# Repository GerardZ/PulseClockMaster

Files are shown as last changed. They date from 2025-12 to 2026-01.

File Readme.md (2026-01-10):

## PulseClock Master

TAGS: slaveClock slave-clock pulseclock pulse-clock secondary-clock slave clock impulse driver masterclock 

### So what is this

This is a NTP-clock which can drive a Pulse Clock/ secondary clock/ slave clock, the type of clock found in schools, stations or other big buildings. Nowadays most of them have been replaced by modern ones, but they still exists. These clocks are driven by a master clock which pulses the slave clocks every minute, where it moves the minute-hand one minute. So it acts as a masterclock for these slave clocks.
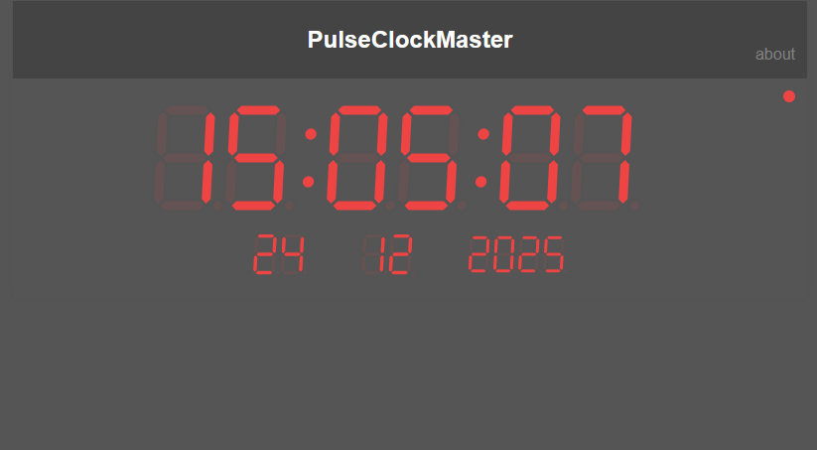
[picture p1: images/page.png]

Webpage is a mere indication of the clock, time is displayed and is coming from the ESP, it is not your pc`s time (though they should be the same). Date is displayed and there is a red dot in the top right corner which displays the state of the pulse, on = poitive, off = negative.

### Why would i need this

You might be a happy owner of such a slave clock, threw it on your attic, like me.  Always asking yourself how to enable that beautiful thing. This can be your savior. 
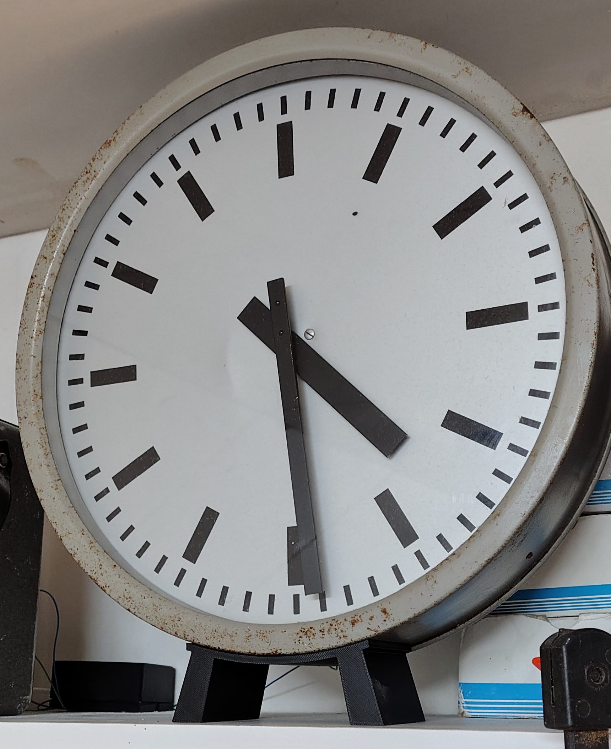
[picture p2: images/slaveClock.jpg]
My Clock:

### What do i need

*   A slave clock obviously
*   This circuitry
*   ESP01 programmer (dont let this frighten you, its a no-brainer)
*   Wifi & internet

### The Circuit

Circuit consist of a 24V power module, 3v3 step down module, an ESP01, opamp & 2 transistor driver.

<div align="center"><a href="images/schema.png" target="_blank">
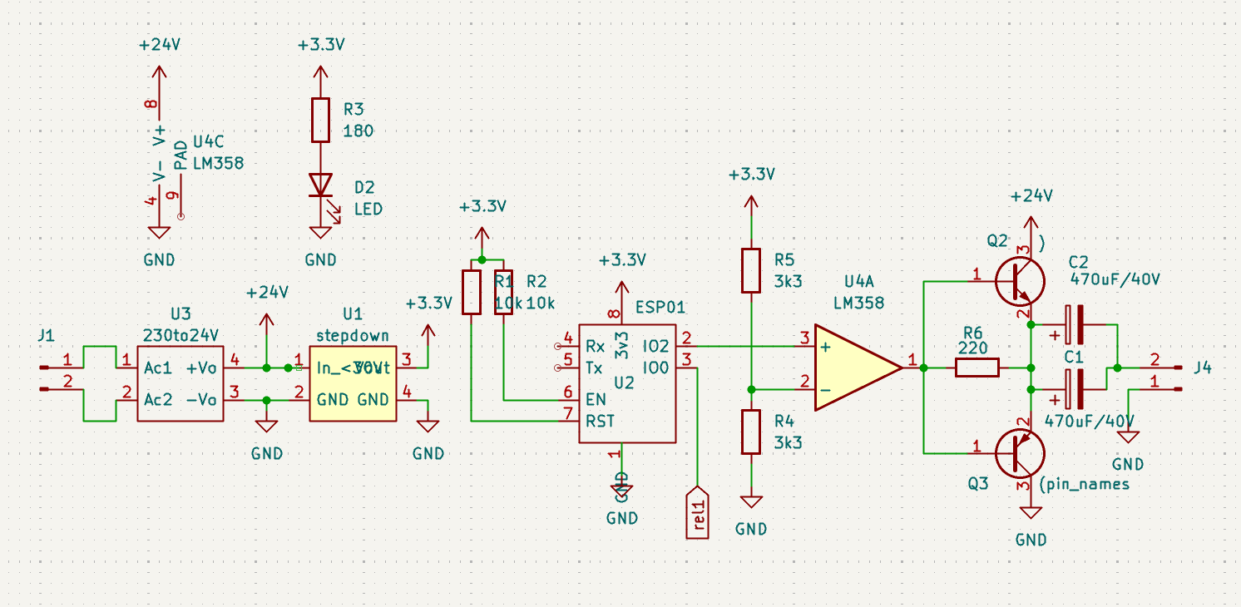
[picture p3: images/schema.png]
  
</a></div>

We need a 24V pulse to drive the clock. Pulses are given every minute where one pulse is positive, the next negative, this is done by the opamp, buffer transistors and the output electrolitic capacitors. The ESP01 pulses the opamp by AND-ing the lsb of the minutes every minute.
Internally time is handled by NTP so we never need to worry over adjusting except for power outages. Even DST is handled !
When you have multiple clocks, you probably get away with two or three, not tested. You could rise capacitance of the output capacitors by 2x 1000uF.
I am running one clock but have only installed one 470uF capacitor. That should give an indication. But I guess not all clock brands have the same load.

### The software

ESP01 firmware has a wifi portal, NTP, a webserver displaying time and pulse status. Time is updated through websockets to the webpage so even for this simple application there is already a lot going on. See for yourself !

### Using

Supply with mains, connect your clock, power up.
On first connection there will be no wifi credentials so the device will go into portal mode and starts is own wifi station with SSID: PulseClockMaster, connect to it (pw: 12345678) and open a page on your webbrowser. The portal page should come up. Enter your wifi credentials an press save. The device will reboot and connect, hopefully, to your wifi. From thereon you should be able to connect via http://PulseClockMaster.local but this depends on your router. If not try
http://PulseClockMaster. If that doesnt work still, find out what ip it is given by your router and connect via ip.
There is only a display of time and date, so this step is not even necessary but it will give you a good idea that it is all functioning well.

You will have to adjust time b hand on the physical clock once. From thereon it will be synced every minute. If you notice the clock keeps behind one minute, reverse polary on the clock and re-adjust. The latter is only nececaity once since the clock pulses depend on wether the minute is odd or even.

You only have to re-adjust after a power-failure.

### Todo\`s

*   make settings for other timezones & DST settings, now only changeable in code
*   power outage handling ?

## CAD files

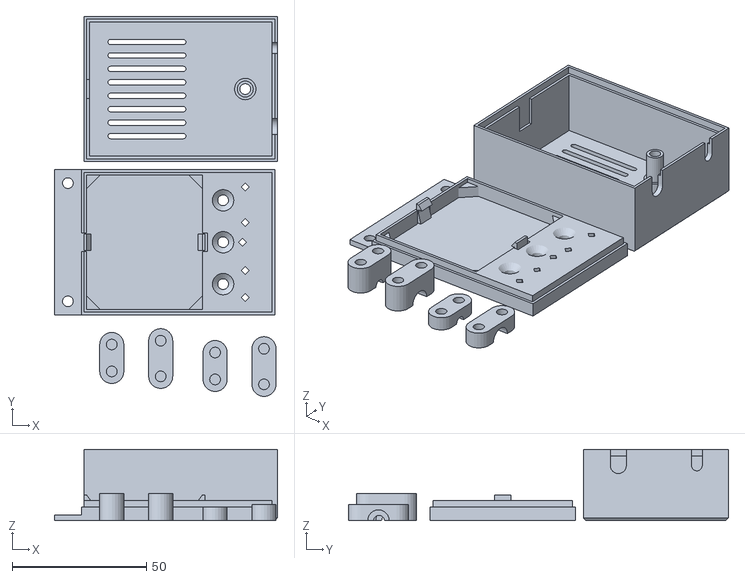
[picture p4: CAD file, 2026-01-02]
ProjectFiles/Housing/housing.stl
83.0 x 141.4 x 26.5

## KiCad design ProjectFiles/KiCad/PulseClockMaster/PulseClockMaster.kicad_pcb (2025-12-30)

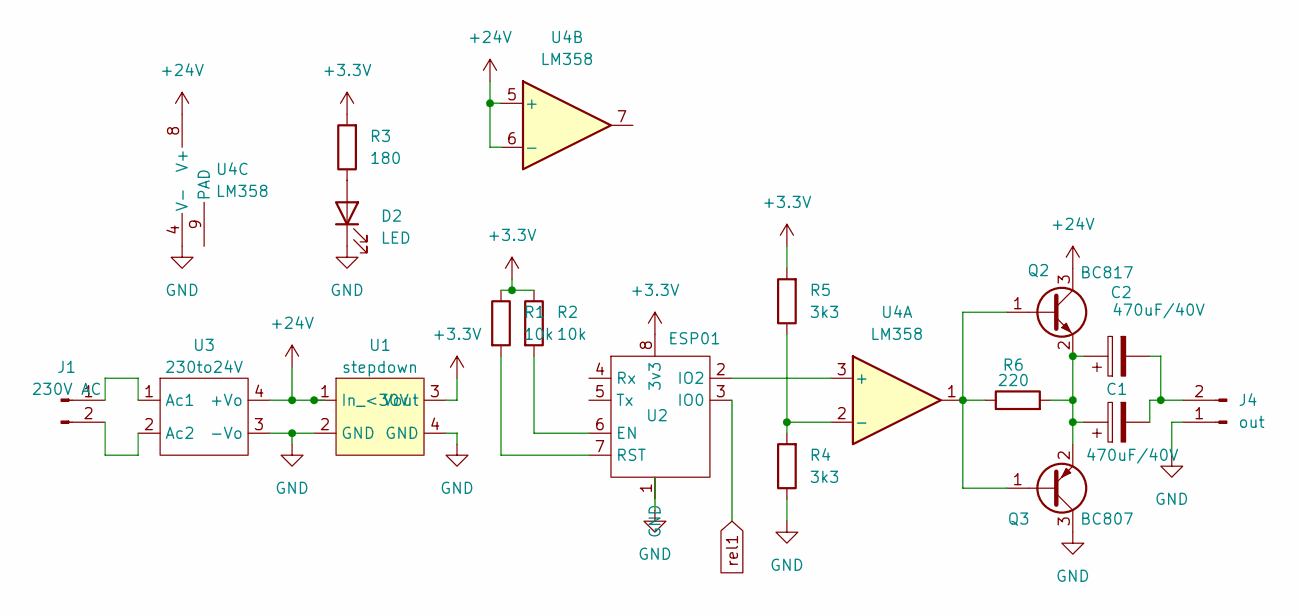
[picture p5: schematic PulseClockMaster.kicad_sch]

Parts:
C1, C2: 470uF/40V; CP_Radial_D8.0mm_P3.80mm
D2: LED; LED_D5.0mm
J1: 230V AC; TerminalBlock_MaiXu_MX126-5.0-02P_1x02_P5.00mm
J4: out; TerminalBlock_4Ucon_1x02_P3.50mm_Horizontal
Q2: BC817; SOT-23
Q3: BC807; SOT-23
R1, R2: 10k; R_0805_2012Metric_Pad1.20x1.40mm_HandSolder
R3: 180; R_0805_2012Metric_Pad1.20x1.40mm_HandSolder
R4, R5: 3k3; R_0805_2012Metric_Pad1.20x1.40mm_HandSolder
R6: 220; R_0805_2012Metric_Pad1.20x1.40mm_HandSolder
U1: stepdown; Mini-Stepdown
U2: ESP01; ESP01_conn+outline
U3: 230to24V; Mini Ac-DC 230 to 24V module EBAY
U4: LM358; SOIC-8_3.9x4.9mm_P1.27mm

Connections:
+3.3V: R1.1, R2.1, R3.2, R5.2, U1.3 (Vout), U2.8 (3v3)
+24V: Q2.3 (C), U1.1 (In_<30V), U3.4 (+Vo), U4.5 (+), U4.6 (-), U4.8 (V+)
GND: D2.1 (K), J4.1, Q3.3 (C), R4.1, U1.2 (GND), U1.4 (GND), U2.1 (GND), U3.3 (-Vo), U4.4 (V-)
unnamed: D2.2 (A), R3.1
unnamed: J1.1, U3.1 (Ac1)
unnamed: J1.2, U3.2 (Ac2)
unnamed: C1.2, C2.2, J4.2
unnamed: Q2.1 (B), Q3.1 (B), R6.1, U4.1
unnamed: C1.1, C2.1, Q2.2 (E), Q3.2 (E), R6.2
unnamed: R2.2, U2.6 (EN)
unnamed: U2.2 (IO2), U4.3 (+)
unnamed: R1.2, U2.7 (RST)
unnamed: R4.2, R5.1, U4.2 (-)
rel1: U2.3 (IO0)

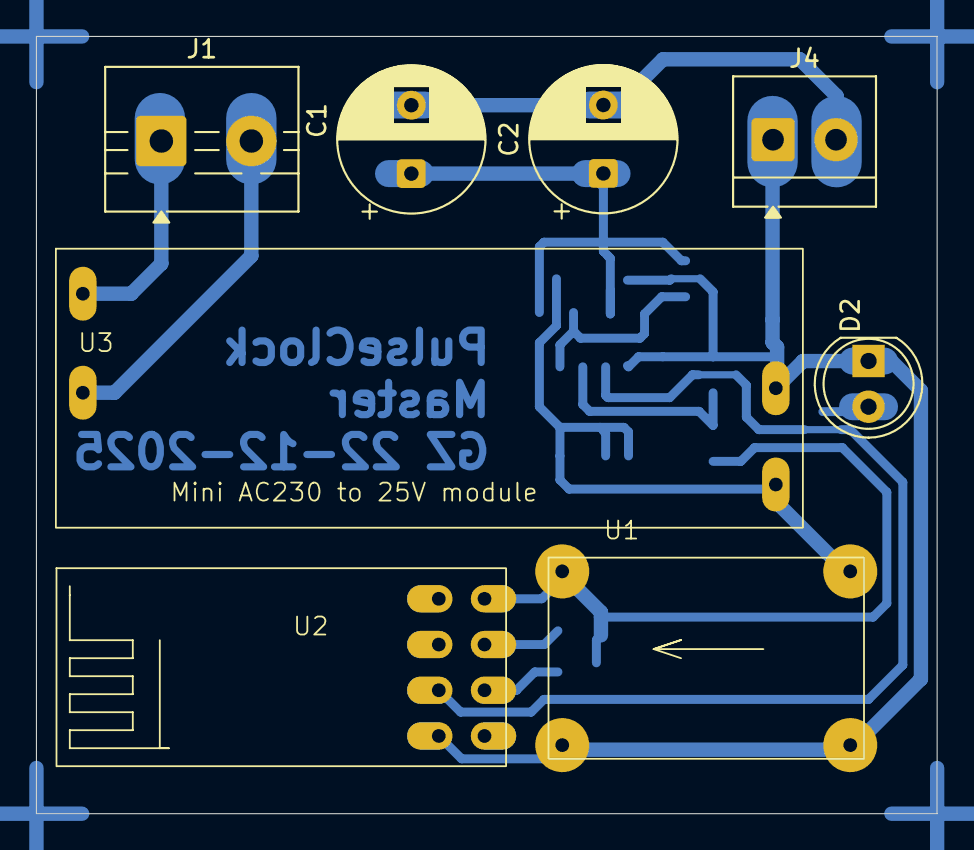
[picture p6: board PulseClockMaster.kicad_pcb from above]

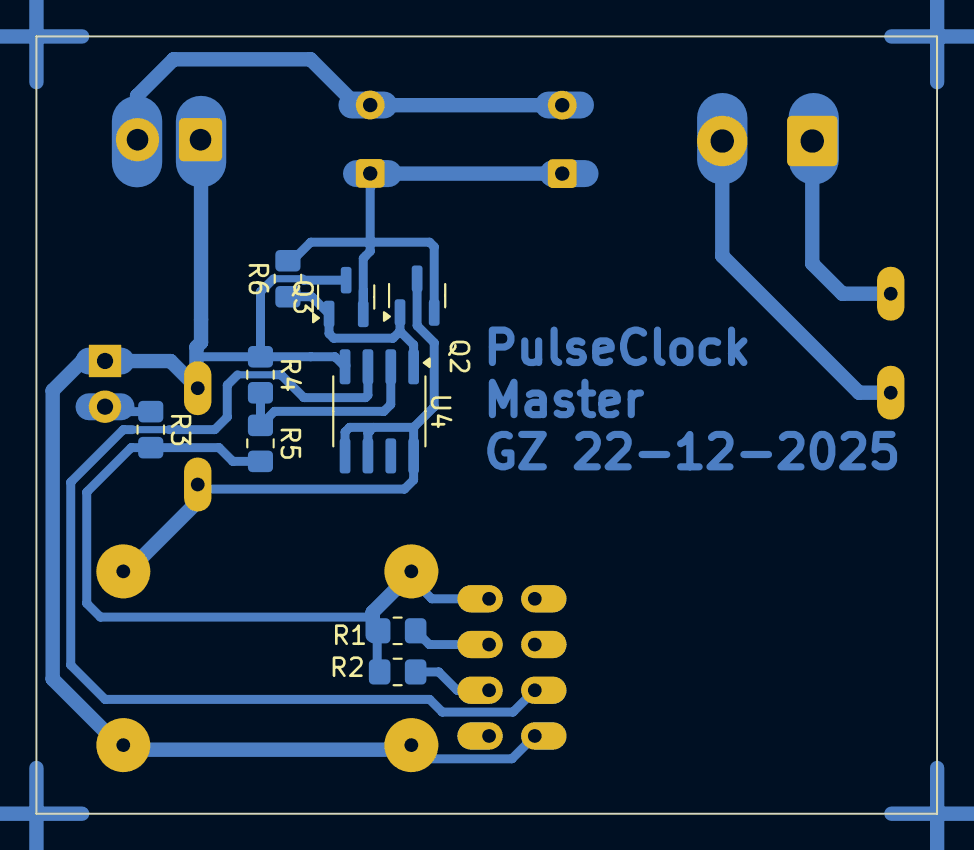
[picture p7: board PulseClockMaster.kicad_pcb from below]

Board: 2 copper layers, 50.0 x 43.2 mm, 17 parts (9 on the bottom side), 13 nets.

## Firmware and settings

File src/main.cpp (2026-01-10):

#include "WifiPortalAndNetwork.h"
#include "timeService.h"
#include "WebServer.h"
#include "websockets.h"


/*

TODO:   DST pause /  run double fast for one hour

*/


#define CLOCKPIN 2

WiFiPortal portal("PulseClockMaster");

uint16_t perfCount;
bool previousDST;
bool ClockPinState;
char lastMessage[200];
uint8_t DstPauseTime = 0;  // this is the number of minutes that should be skipped if we come from DST
uint8_t DstExtraTime = 0;    // this holds the number of minutes that should be added when we go to DST

void toggleClockPin(int minute)
{
  if (DstPauseTime){     // we come from DST, hold for 1 hour
    DstPauseTime--;      // keep count
    return;
  }
  
  ClockPinState = (minute & 1);   // clockpulse polarity is in sync with minute, this way we always have same polarity so we never need to alter polarity on the clock itself once it is correct.
  pinMode(CLOCKPIN, OUTPUT);
  digitalWrite(CLOCKPIN, ClockPinState);
}

void toggleDSTClockpin(){   // this is used when going to DST, remember we need to call this twice in one minute to keep in sync with normal minute toggle. So call it on 20 & 40st second.
  ClockPinState = !ClockPinState;
  pinMode(CLOCKPIN, OUTPUT);
  digitalWrite(CLOCKPIN, ClockPinState);
}

void sendUpdateToCLients(const struct tm *tm)
{
  sprintf(lastMessage, R"({"year":%d, "month":%d, "mday":%d, "wday":%d, "DST":%d, "time": "%2d:%02d:%02d", "pulse": %d})", tm->tm_year - 100, tm->tm_mon + 1, tm->tm_mday, tm->tm_wday, tm->tm_isdst, tm->tm_hour, tm->tm_min, tm->tm_sec, ClockPinState);
  WsSendMessage(lastMessage);
}

void handleMinute(const struct tm *tm)
{
  toggleClockPin(tm->tm_min);
  sendUpdateToCLients(tm);
  Serial.printf("Time: %2d:%02d:%02d\n", tm->tm_hour, tm->tm_min, tm->tm_sec);
}

void handleSecond(const struct tm *tm)
{
    sendUpdateToCLients(tm);

    // handle to DST, we do 60 extra pulses on :20 and :40 second after DST has become active
    // note that we toggle twice in a minute to keep in sync with normal minute pulse.
    if ((tm->tm_sec == 20 or tm->tm_sec == 40) and !DstExtraTime){
      toggleDSTClockpin();
      DstExtraTime--;                                                // track count
    }
}

void handleHour(const struct tm *tm)
{
  // check here whether DST has changed
  if (previousDST != tm->tm_isdst)
  {
    // we have a change, beware of startup....
    previousDST = tm->tm_isdst;
    if (tm->tm_isdst)   // we go into DST, add one hour
    {
      // we switched to DST, we need to let the clock 1 hour extra
      DstExtraTime = 59;
    }
    else
    {
      // we switched from DST to normal, we need to let the clock pause for one hour...
      DstPauseTime = 59;
    }
  }
}

void HandleWsMessage(uint8_t *message, size_t len, AsyncWebSocketClient *client)
{
  // gets called when there is an incoming websockets message.
}

void HandleNewWsClient(AsyncWebSocketClient *client)
{
  // new client...
  IPAddress remoteIp = client->remoteIP();
  WsSendMessage(lastMessage, client->id());
}


void waitForTimeSync() {
  time_t now = time(nullptr);
  int retries = 0;
  while (now < 8 * 3600 * 2 && retries < 20) { // roughly checks if time is before year ~2000
    delay(500);
    Serial.print("#");
    now = time(nullptr);
    retries++;
  }

  if (now < 8 * 3600 * 2) {
    Serial.println("\nFailed to sync time.");
  } else {
    Serial.println("\nTime synced.");
  }
}

void initDST(){
  time_t now;
  struct tm tm_now;

    time(&now);
    localtime_r(&now, &tm_now);
    previousDST = tm_now.tm_isdst;
}

void setup()
{
  delay(2000);
  Serial.begin(74880);
  Serial.println("Boot OK");
  delay(2000);
  portal.begin();
  // we now have wifi...

  Serial.println("Wifi connected...");

  portal.SetupNtp();

  AsyncWebServer *server = SetupWebserver();
  SetupWebSockets(server, HandleWsMessage, HandleNewWsClient);

  waitForTimeSync();  // we need a synced time for initDST
  initDST();          // we need to set this at startup, otherwise clock will start weird when DST is true.

  TimeService_Init(handleSecond, handleMinute, nullptr, nullptr);
}

void loop()
{
  perfCount++;
  TimeService_Tick();
  delay(1);
}

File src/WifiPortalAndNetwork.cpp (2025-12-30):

// WiFiPortal.cpp
#include "WifiPortalAndNetwork.h"

WiFiPortal::WiFiPortal(const String &deviceName)
    : server(80), deviceName(deviceName) {}

void WiFiPortal::begin()
{
    EEPROM.begin(EEPROM_SIZE);

    String ssid, pass;
    loadCredentials(ssid, pass);

    WiFi.mode(WIFI_STA);
    WiFi.setHostname(deviceName.c_str());
    WiFi.begin(ssid.c_str(), pass.c_str());

    Serial.print("Connecting to WiFi");
    for (int i = 0; i < 20; i++)
    {
        if (WiFi.status() == WL_CONNECTED)
        {
            Serial.println("\nConnected!");
            Serial.println(WiFi.localIP());
            return;
        }
        delay(500);
        Serial.print(".");
    }

    Serial.println("\nWiFi failed. Starting captive portal...");
    startCaptivePortal();
}

bool WiFiPortal::isWiFiConnected()
{
    return WiFi.status() == WL_CONNECTED;
}

void WiFiPortal::startCaptivePortal()
{
    WiFi.softAP(deviceName.c_str(), ap_password);
    delay(100);
    IPAddress myIP = WiFi.softAPIP();
    dnsServer.start(DNS_PORT, "*", myIP);

    server.on("/", HTTP_GET, std::bind(&WiFiPortal::handleRoot, this, std::placeholders::_1));
    server.on("/submit", HTTP_POST, std::bind(&WiFiPortal::handleSubmit, this, std::placeholders::_1));

    // Note: scan gives problems under softAP !

    server.onNotFound([](AsyncWebServerRequest *request)
                      { request->redirect("/"); });

    server.begin();
    Serial.println("Captive portal started.");

    while (true)
    {
        yield();
    }
}

void WiFiPortal::handleRoot(AsyncWebServerRequest *request)
{
    String html = R"rawliteral(
<html>
<head>
  <title>)rawliteral" +
                  deviceName + R"rawliteral( WiFi Config</title>
  <style>
    body {
      background-color: #f0f0f0;
      font-family: sans-serif;
      display: flex;
      justify-content: center;
      align-items: center;
      height: 100vh;
      margin: 0;
    }

    .form-container {
      background-color: #fff;
      padding: 20px 30px;
      border-radius: 8px;
      box-shadow: 0 0 10px rgba(0,0,0,0.2);
      text-align: center;
    }

    input[type="text"], input[type="password"] {
      width: 100%;
      padding: 8px;
      margin: 8px 0;
      border: 1px solid #ccc;
      border-radius: 4px;
    }

    input[type="submit"] {
      background-color: #4CAF50;
      color: white;
      padding: 10px 15px;
      border: none;
      border-radius: 4px;
      cursor: pointer;
    }

    input[type="submit"]:hover {
      background-color: #45a049;
    }
  </style>
</head>
<body>
  <div class="form-container">
  <h2>)rawliteral" +
                  deviceName + R"rawliteral( WiFi Setup</h2>
    <h3>Configure WiFi</h3>
    <form action="/submit" method="POST">
        <input type="text" name="ssid" placeholder="WiFi SSID" required><br>
        <input type="password" name="pass" placeholder="WiFi Password" required><br>
        <input type="submit" value="Save">
    </form>
  </div>
</body>
</html>
)rawliteral";
    request->send(200, "text/html", html);
}

void WiFiPortal::handleSubmit(AsyncWebServerRequest *request)
{
    if (request->hasParam("ssid", true) && request->hasParam("pass", true))
    {
        String ssid = request->getParam("ssid", true)->value();
        String pass = request->getParam("pass", true)->value();
        saveCredentials(ssid, pass);

        request->send(200, "text/html", "<h2>Saved. Rebooting...</h2>");
        delay(5000);
        ESP.restart();
    }
    else
    {
        request->send(400, "text/plain", "Missing parameters");
    }
}

void WiFiPortal::loadCredentials(String &ssid, String &pass)
{
    char ssidBuf[32], passBuf[32];
    for (int i = 0; i < 32; i++)
    {
        ssidBuf[i] = EEPROM.read(SSID_ADDR + i);
        passBuf[i] = EEPROM.read(PASS_ADDR + i);
    }
    ssidBuf[31] = 0;
    passBuf[31] = 0;
    ssid = String(ssidBuf);
    pass = String(passBuf);
}

void WiFiPortal::saveCredentials(const String &ssid, const String &pass)
{
    for (int i = 0; i < 32; i++)
    {
        EEPROM.write(SSID_ADDR + i, i < ssid.length() ? ssid[i] : 0);
        EEPROM.write(PASS_ADDR + i, i < pass.length() ? pass[i] : 0);
    }
    EEPROM.commit();
}

void WiFiPortal::clearWifiCredentials()
{
    EEPROM.write(SSID_ADDR, 0);
    EEPROM.write(PASS_ADDR, 0);
    EEPROM.commit();
    Serial.println("\nWiFi credentials cleared, rebooting in 5 seconds...");
    delay(5000);
    ESP.restart();
}

IPAddress WiFiPortal::DnsLookup(const char *host)
{
  IPAddress ip;
  if (WiFi.hostByName(host, ip)) {
    Serial.print("DNS Lookup successful. IP Address: ");
    Serial.println(ip);
  } else {
    Serial.println("DNS Lookup failed.");
  }

  return ip;
}

IPAddress WiFiPortal::GetIpAddress()
{
    return WiFi.localIP();
}

IPAddress WiFiPortal::GetBroadcastAddress()
{
  IPAddress broadcastAddress;
  IPAddress wifiIp = WiFi.localIP();
  IPAddress mask = WiFi.subnetMask();

  for (int i = 0; i < 4; i++)
  {
    broadcastAddress[i] = wifiIp[i] | ~mask[i];
  }
  return broadcastAddress;
}

void WiFiPortal::SetupNtp(const char *TimeZoneString, const char *NtpServer)
{
  configTime(TimeZoneString, NtpServer); // --> This is al for NTP to configure...
}

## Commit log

2025-12-22 Added PCB
    [PulseClockMaster.kicad_pcb, PulseClockMaster.kicad_sch]
2025-12-22 readme update
    [PulseClockMaster.kicad_pcb]
2025-12-22 issue in PCB
    [PulseClockMaster.kicad_pcb]
2025-12-24 PCB & Javascript updates
    [PulseClockMaster.kicad_pcb, PulseClockMaster.kicad_sch]
2025-12-27 Readme update, small PCB update
    [PulseClockMaster.kicad_pcb]
2025-12-30 some cleanup
    [PulseClockMaster.kicad_pcb, zones.csv]
2026-01-02 housing added
    [housing.stl]
